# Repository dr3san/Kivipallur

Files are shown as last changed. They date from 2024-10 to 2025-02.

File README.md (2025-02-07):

# Kivipallur
A split ergo keyboard with a 25 mm thumb trackball.

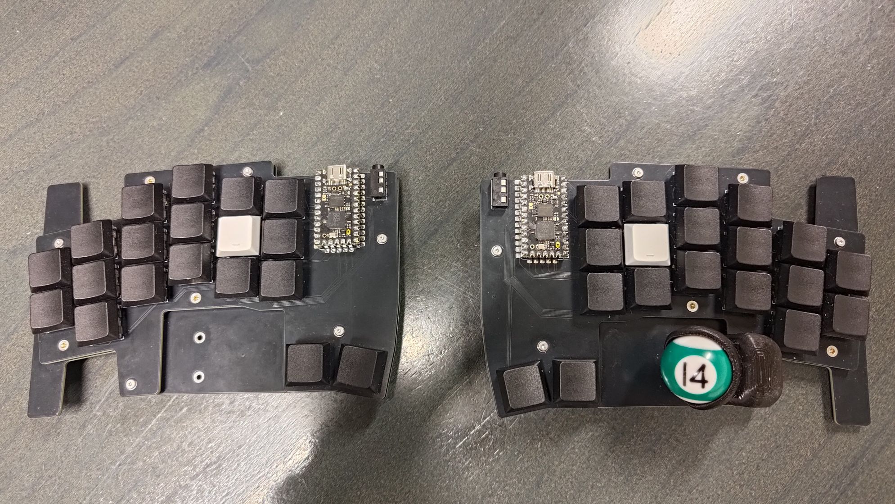
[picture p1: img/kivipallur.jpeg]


## Features
- 38 keys
- split, colstag
- diodeless, only 0xCB Helios compatible (good amount of pins, no separate reset switch needed)
- hot-swap Choc v1
- 25 mm trackball with PMW3360 breakout

Layout was created with Ergogen.
I tested it by printing it out on paper and cutting out switch holes from cardboard.

Since I opted for low-profile switches, I also tried a smaller ball, since a ball holder design was available on Thingiverse.
I didn't make a CAD model and due to not accounting for everything in my head, had to modify the holder height a bit.
But it doesn't make it any more uncomfortable to use.

Finding a 25 mm trackball proved difficult, so I tried a steel ball, a silicon nitride ball, and a kids pool set 25 mm ball.
Surprisingly, the pool ball worked best.
Coming from a standard 34 mm ball, I don't feel the smaller ball performs worse.
The trackball sits on 2 mm silicon nitride static bearings. No noticable stiction, friction reasonable for flicks.

QMK config found in my `qmk-userspace` fork.

I started out with 3D printed tenting feet, but moved on to camera mounts.
Bottom plate has M2 holes, which allow for heat-set inserts in addons.
Tenting feet and camera mount attachment with 3D printed thread designed myself.

## Thank-yous
Yowkees for the Keyball

GEIST for the Totem

MrZealot for Ergogen

FlatFootFox for Ergogen tutorials

kepeo for [25 mm trackball holder](https://www.thingiverse.com/thing:6719828)

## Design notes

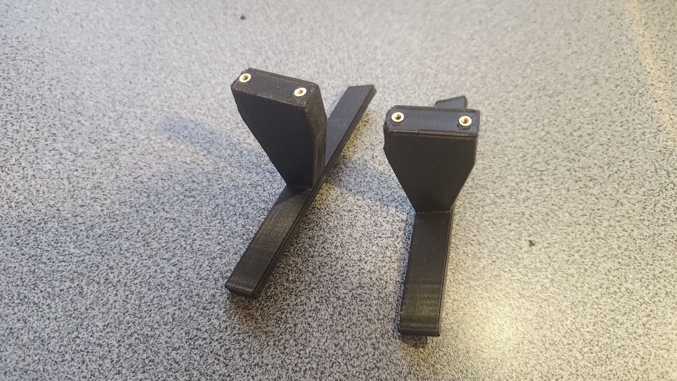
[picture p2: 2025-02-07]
img/tenting-feet.jpeg

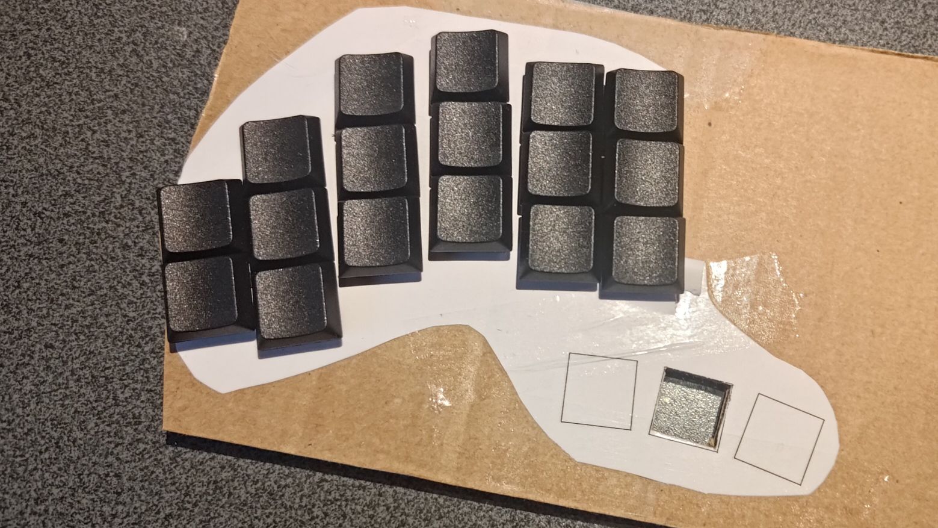
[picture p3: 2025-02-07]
img/prototyping.jpeg

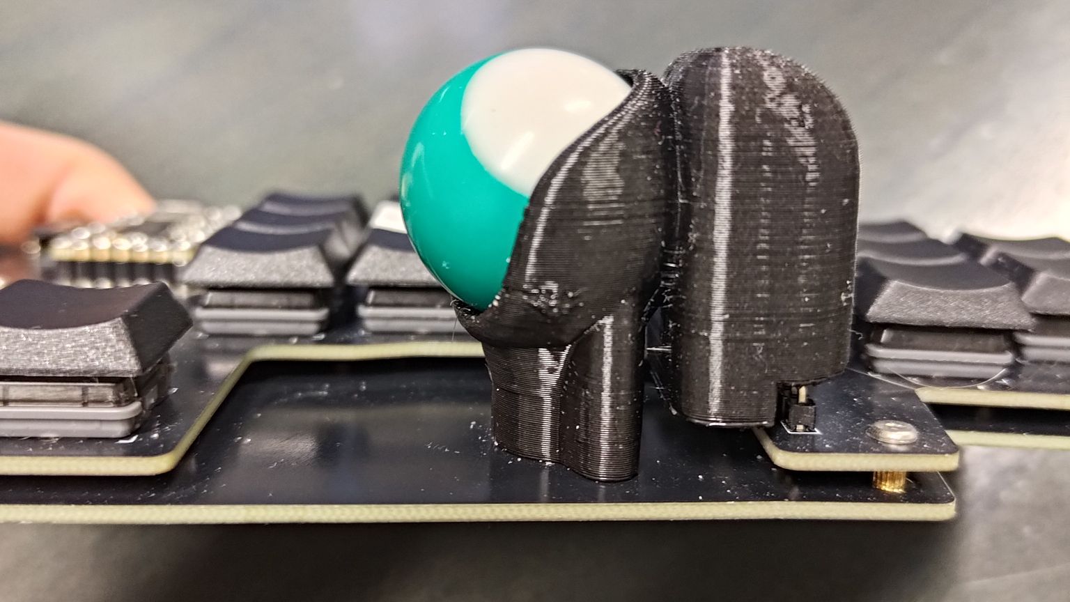
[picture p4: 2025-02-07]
img/trackball-holder.jpeg

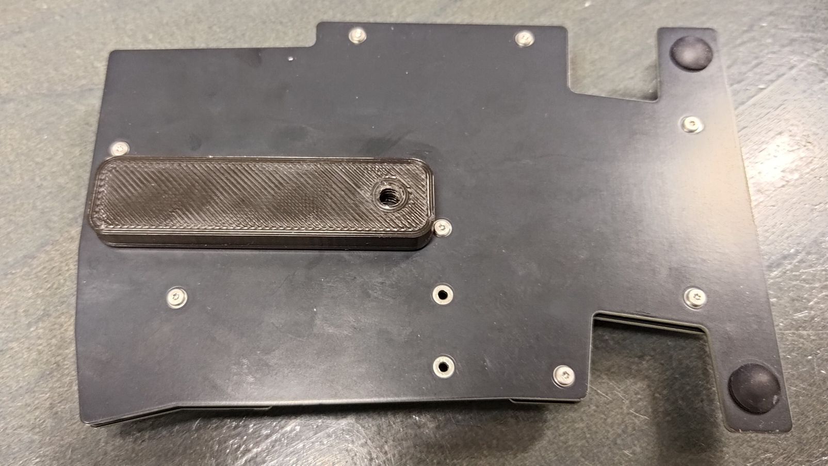
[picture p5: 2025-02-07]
img/camera-mount.jpeg

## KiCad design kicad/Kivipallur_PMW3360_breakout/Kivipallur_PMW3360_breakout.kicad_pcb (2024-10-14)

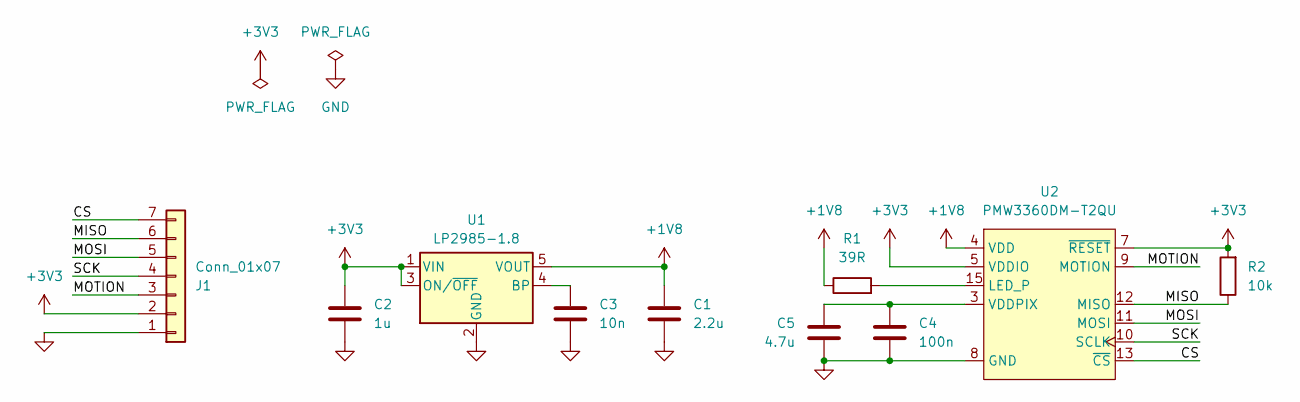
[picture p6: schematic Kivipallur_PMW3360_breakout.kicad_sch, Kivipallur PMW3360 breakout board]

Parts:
C1: 2.2u; C_0603_1608Metric_Pad1.08x0.95mm_HandSolder
C2: 1u; C_0603_1608Metric_Pad1.08x0.95mm_HandSolder
C3: 10n; C_0603_1608Metric_Pad1.08x0.95mm_HandSolder
C4: 100n; C_0603_1608Metric_Pad1.08x0.95mm_HandSolder
C5: 4.7u; C_0603_1608Metric_Pad1.08x0.95mm_HandSolder
J1: Conn_01x07; PinHeader_1x07_P2.54mm_Vertical
R1: 39R; R_0603_1608Metric_Pad0.98x0.95mm_HandSolder
R2: 10k; R_0603_1608Metric_Pad0.98x0.95mm_HandSolder
U1: LP2985-1.8; SOT-23-5
U2: PMW3360DM-T2QU; PMW3360DM-T2QU 16Pin

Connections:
+1V8: C1.1, R1.1, U1.5 (VOUT), U2.4 (VDD)
+3V3: C2.1, J1.2, R2.2, U1.1 (VIN), U1.3 (ON/~OFF), U2.5 (VDDIO), U2.7 (~RESET)
/CS: J1.7, U2.13 (~CS)
/MISO: J1.6, R2.1, U2.12 (MISO)
/MOSI: J1.5, U2.11 (MOSI)
/MOTION: J1.3, U2.9 (MOTION)
/SCK: J1.4, U2.10 (SCLK)
GND: C1.2, C2.2, C3.2, C4.1, C5.2, J1.1, U1.2 (GND), U2.8 (GND)
unnamed: C3.1, U1.4 (BP)
unnamed: R1.2, U2.15 (LED_P)
unnamed: C4.2, C5.1, U2.3 (VDDPIX)

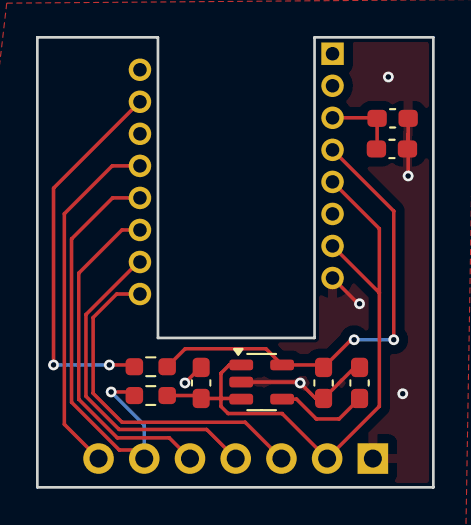
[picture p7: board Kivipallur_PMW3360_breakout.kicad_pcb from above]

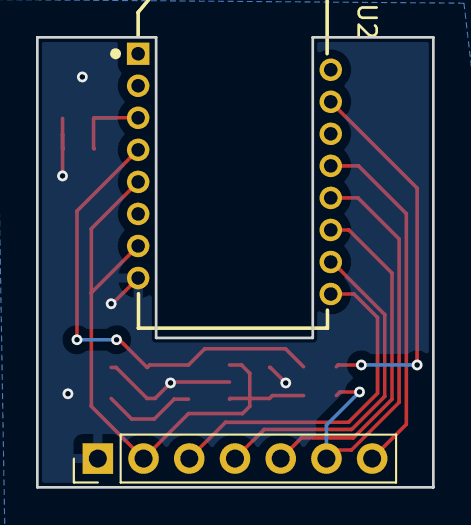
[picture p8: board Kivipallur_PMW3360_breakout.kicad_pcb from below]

Board: 2 copper layers, 22.0 x 25.0 mm, 10 parts (2 on the bottom side), 11 nets.

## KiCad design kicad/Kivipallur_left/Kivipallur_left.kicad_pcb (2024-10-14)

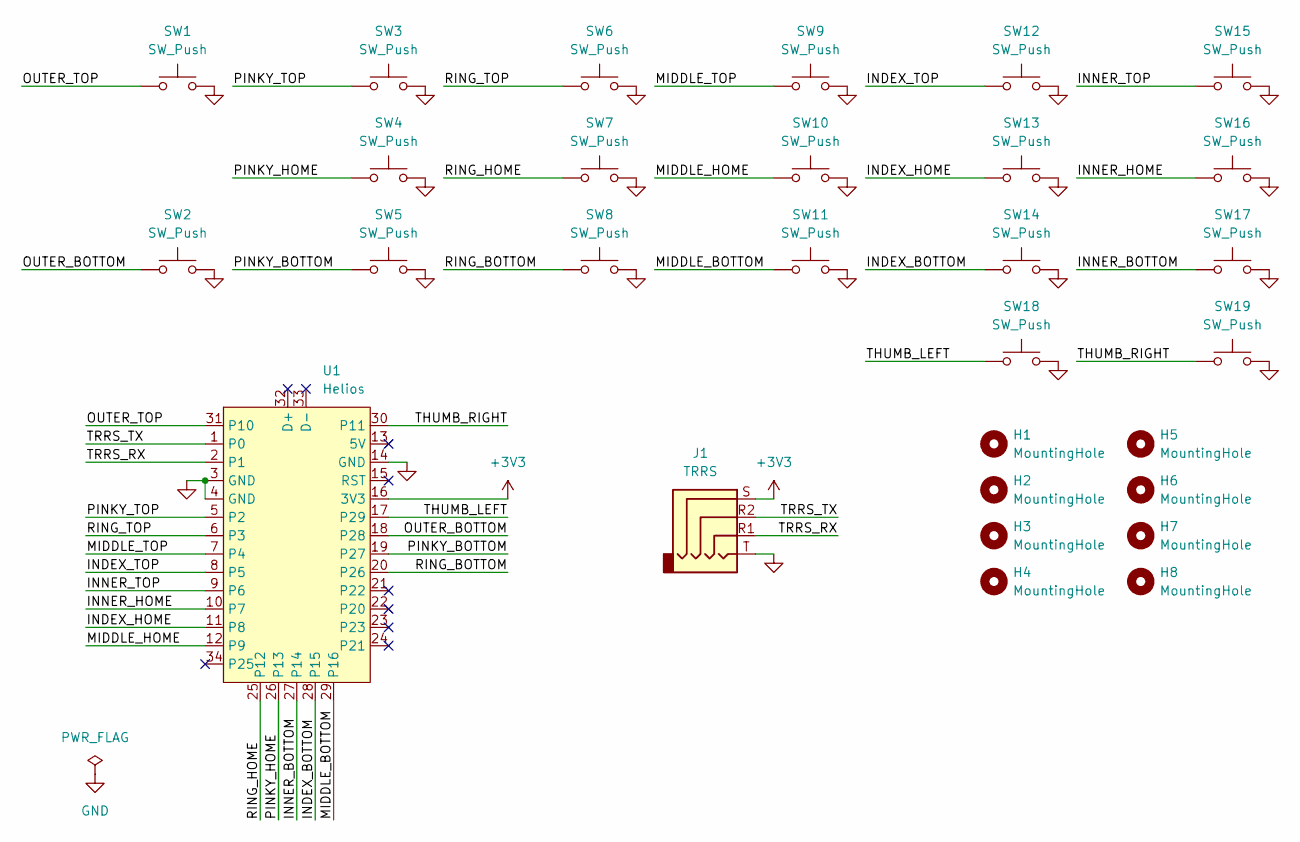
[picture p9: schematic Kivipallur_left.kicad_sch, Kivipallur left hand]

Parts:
H1, H2, H3, H4, H5, H6, H7, H8: MountingHole; MountingHole_2.2mm_M2_Pad
J1: TRRS; TRRS-PJ-320A
SW1, SW2, SW3, SW4, SW5, SW6, SW7, SW8, SW9, SW10, SW11, SW12, SW13, SW14, SW15, SW16, SW17, SW18, SW19: SW_Push; Kailh_socket_PG1350_optional
U1: Helios; Helios_ACH

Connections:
+3V3: J1.S, U1.16 (3V3)
/INDEX_BOTTOM: SW14.1, U1.28 (P15)
/INDEX_HOME: SW13.1, U1.11 (P8)
/INDEX_TOP: SW12.1, U1.8 (P5)
/INNER_BOTTOM: SW17.1, U1.27 (P14)
/INNER_HOME: SW16.1, U1.10 (P7)
/INNER_TOP: SW15.1, U1.9 (P6)
/MIDDLE_BOTTOM: SW11.1, U1.29 (P16)
/MIDDLE_HOME: SW10.1, U1.12 (P9)
/MIDDLE_TOP: SW9.1, U1.7 (P4)
/OUTER_BOTTOM: SW2.1, U1.18 (P28)
/OUTER_TOP: SW1.1, U1.31 (P10)
/PINKY_BOTTOM: SW5.1, U1.19 (P27)
/PINKY_HOME: SW4.1, U1.26 (P13)
/PINKY_TOP: SW3.1, U1.5 (P2)
/RING_BOTTOM: SW8.1, U1.20 (P26)
/RING_HOME: SW7.1, U1.25 (P12)
/RING_TOP: SW6.1, U1.6 (P3)
/THUMB_LEFT: SW18.1, U1.17 (P29)
/THUMB_RIGHT: SW19.1, U1.30 (P11)
/TRRS_RX: J1.R1, U1.2 (P1)
/TRRS_TX: J1.R2, U1.1 (P0)
GND: J1.T, SW1.2, SW2.2, SW3.2, SW4.2, SW5.2, SW6.2, SW7.2, SW8.2, SW9.2, SW10.2, SW11.2, SW12.2, SW13.2, SW14.2, SW15.2, SW16.2, SW17.2, SW18.2, SW19.2, U1.3 (GND), U1.4 (GND), U1.14 (GND)

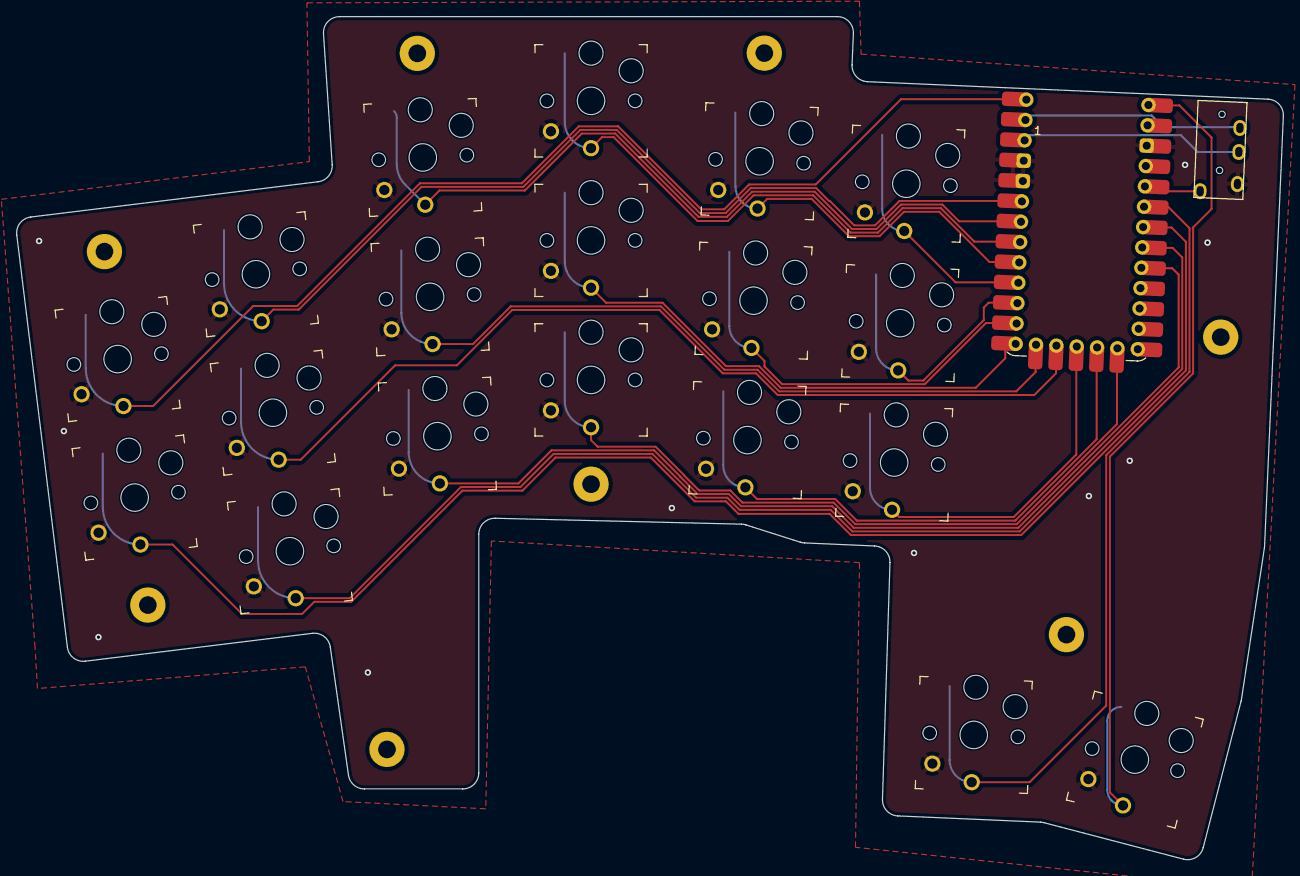
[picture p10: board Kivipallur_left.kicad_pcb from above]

Board: 2 copper layers, 158.0 x 105.1 mm, 29 parts (0 on the bottom side), 23 nets.

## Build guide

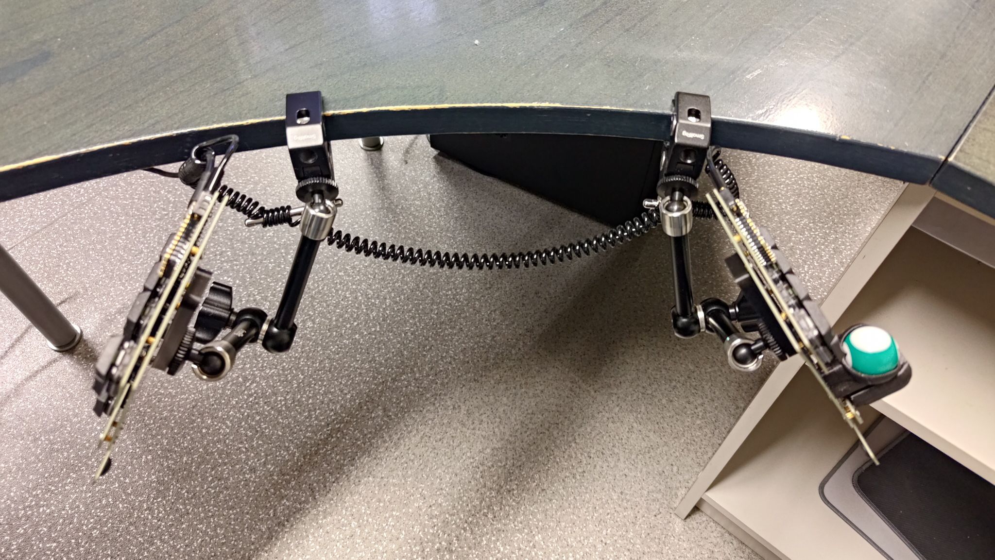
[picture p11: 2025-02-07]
img/setup.jpeg

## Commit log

2024-10-03 Add Kicad symbol and footprint libraries, left hand schematic
    [Kivipallur_left.kicad_pcb, Kivipallur_left.kicad_sch]
2024-10-03 Add mounting holes to left hand schematic
    [Kivipallur_left.kicad_sch]
2024-10-03 Add board and plate layout
2024-10-04 Add left hand PCB design and gerbers
    [Kivipallur_left.kicad_sch]
2024-10-07 Add PMW3360 breakout board Kicad project
    [Kivipallur_PMW3360_breakout.kicad_pcb, Kivipallur_PMW3360_breakout.kicad_sch, Kivipallur_left.kicad_pcb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]
2024-10-09 Add final ergogen config
    [Kivipallur_left.kicad_pcb]
2024-10-09 Change bottom plate
2024-10-10 Add bottom plate
2024-10-11 Add left hand PCB
    [Kivipallur_left.kicad_pcb, Kivipallur_left.kicad_sch]
2024-10-13 Add right hand schematic and partial PCB
    [Kivipallur_PMW3360_breakout.kicad_pcb, Kivipallur_right.kicad_pcb, Kivipallur_right.kicad_sch]
2024-10-14 Add finished right hand PCB
    [Kivipallur_left.kicad_pcb, Kivipallur_right.kicad_pcb]
2024-10-14 Add plate PCB
    [Kivipallur_plate.kicad_pcb, Kivipallur_plate.kicad_sch]
2024-10-14 Revise plate
2024-10-14 Change PMW3360 footprint outline, finalize others
    [Kivipallur_PMW3360_breakout.kicad_pcb, Kivipallur_left.kicad_pcb, Kivipallur_plate.kicad_pcb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]
2024-10-14 Add gerbers for all, order 1st prototype
    [Kivipallur_PMW3360_breakout-B_Cu.gbl, Kivipallur_PMW3360_breakout-B_Mask.gbs, Kivipallur_PMW3360_breakout-B_Paste.gbp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]
